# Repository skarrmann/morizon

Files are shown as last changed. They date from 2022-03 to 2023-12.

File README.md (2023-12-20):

# Morizon Keyboard

Morizon is a 5-row version of the Horizon keyboard.

This project is a direct modification of the Horizon project. The schematic and PCBs have been modified to support this 5-row layout.

As with Horizon, two separate PCB designs are available in the [`gerbers`](gerbers) folder: one for MX switches (19mm x 19mm spacing), and one for Choc switches (18mm x 17mm spacing).

Please refer to the [Horizon keyboard repository](https://github.com/skarrmann/horizon) for project documentation. Only Morizon-specific details are noted below!

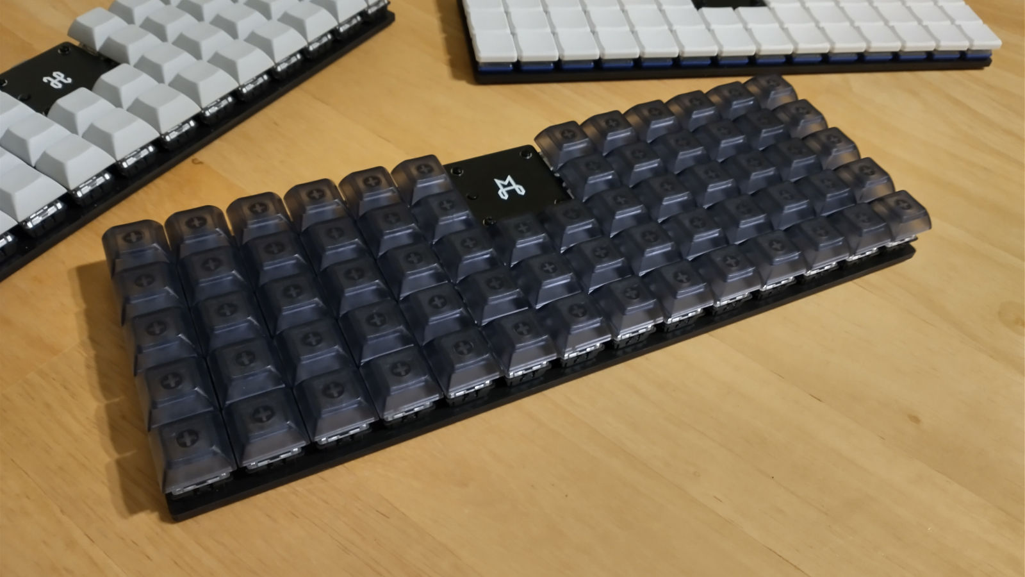
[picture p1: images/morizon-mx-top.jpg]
Morizon MX top photo


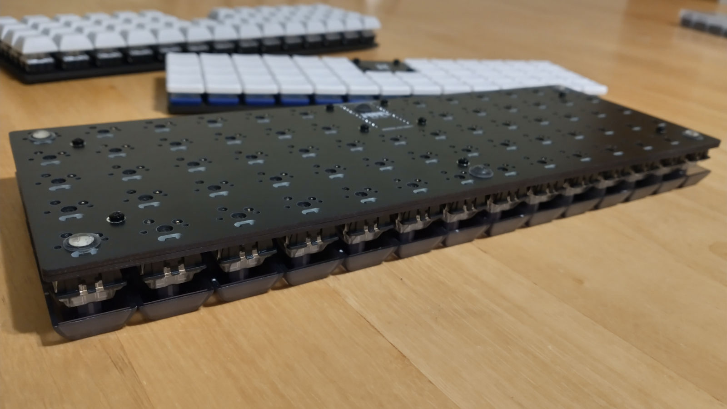
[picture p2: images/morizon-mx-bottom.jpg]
Morizon MX bottom photo


## Keyboard firmware

* [QMK](https://github.com/qmk/qmk_firmware/tree/master/keyboards/morizon)
* ZMK
    * Morizon shield definition is in [skarrmann's zmk-config](https://github.com/skarrmann/zmk-config)

## Bill of materials

Same as the [Horizon keyboard BOM](https://github.com/skarrmann/horizon/#bill-of-materials), but you will also need:

* Morizon PCBs (instead of Horizon PCBs)
* 14 more keyswitches
* 14 more keycaps
* 14 more 1N4148 SOD-123 diodes
* 1 more M2 6mm screw
* 1 more M2 nut

## Revision History

* **Rev1** (2022-02-05)
    * PCB: Create MX and Choc boards with bottom and top plates (based on Horizon).
    * Schematic: Wire as 66 key 10x7 matrix.
* **Rev1.1** (2022-03-21)
    * PCB, Schematic: No physical changes. Files upgraded to KiCad 6, and Gerber files regenerated using Horizon Board Producer 2.3.
* **Rev1.2** (2023-11-09)
    * PCB, Schematic: No physical changes. Files upgraded to KiCad 7, and Gerber files regenerated using Horizon Board Producer 2.4.

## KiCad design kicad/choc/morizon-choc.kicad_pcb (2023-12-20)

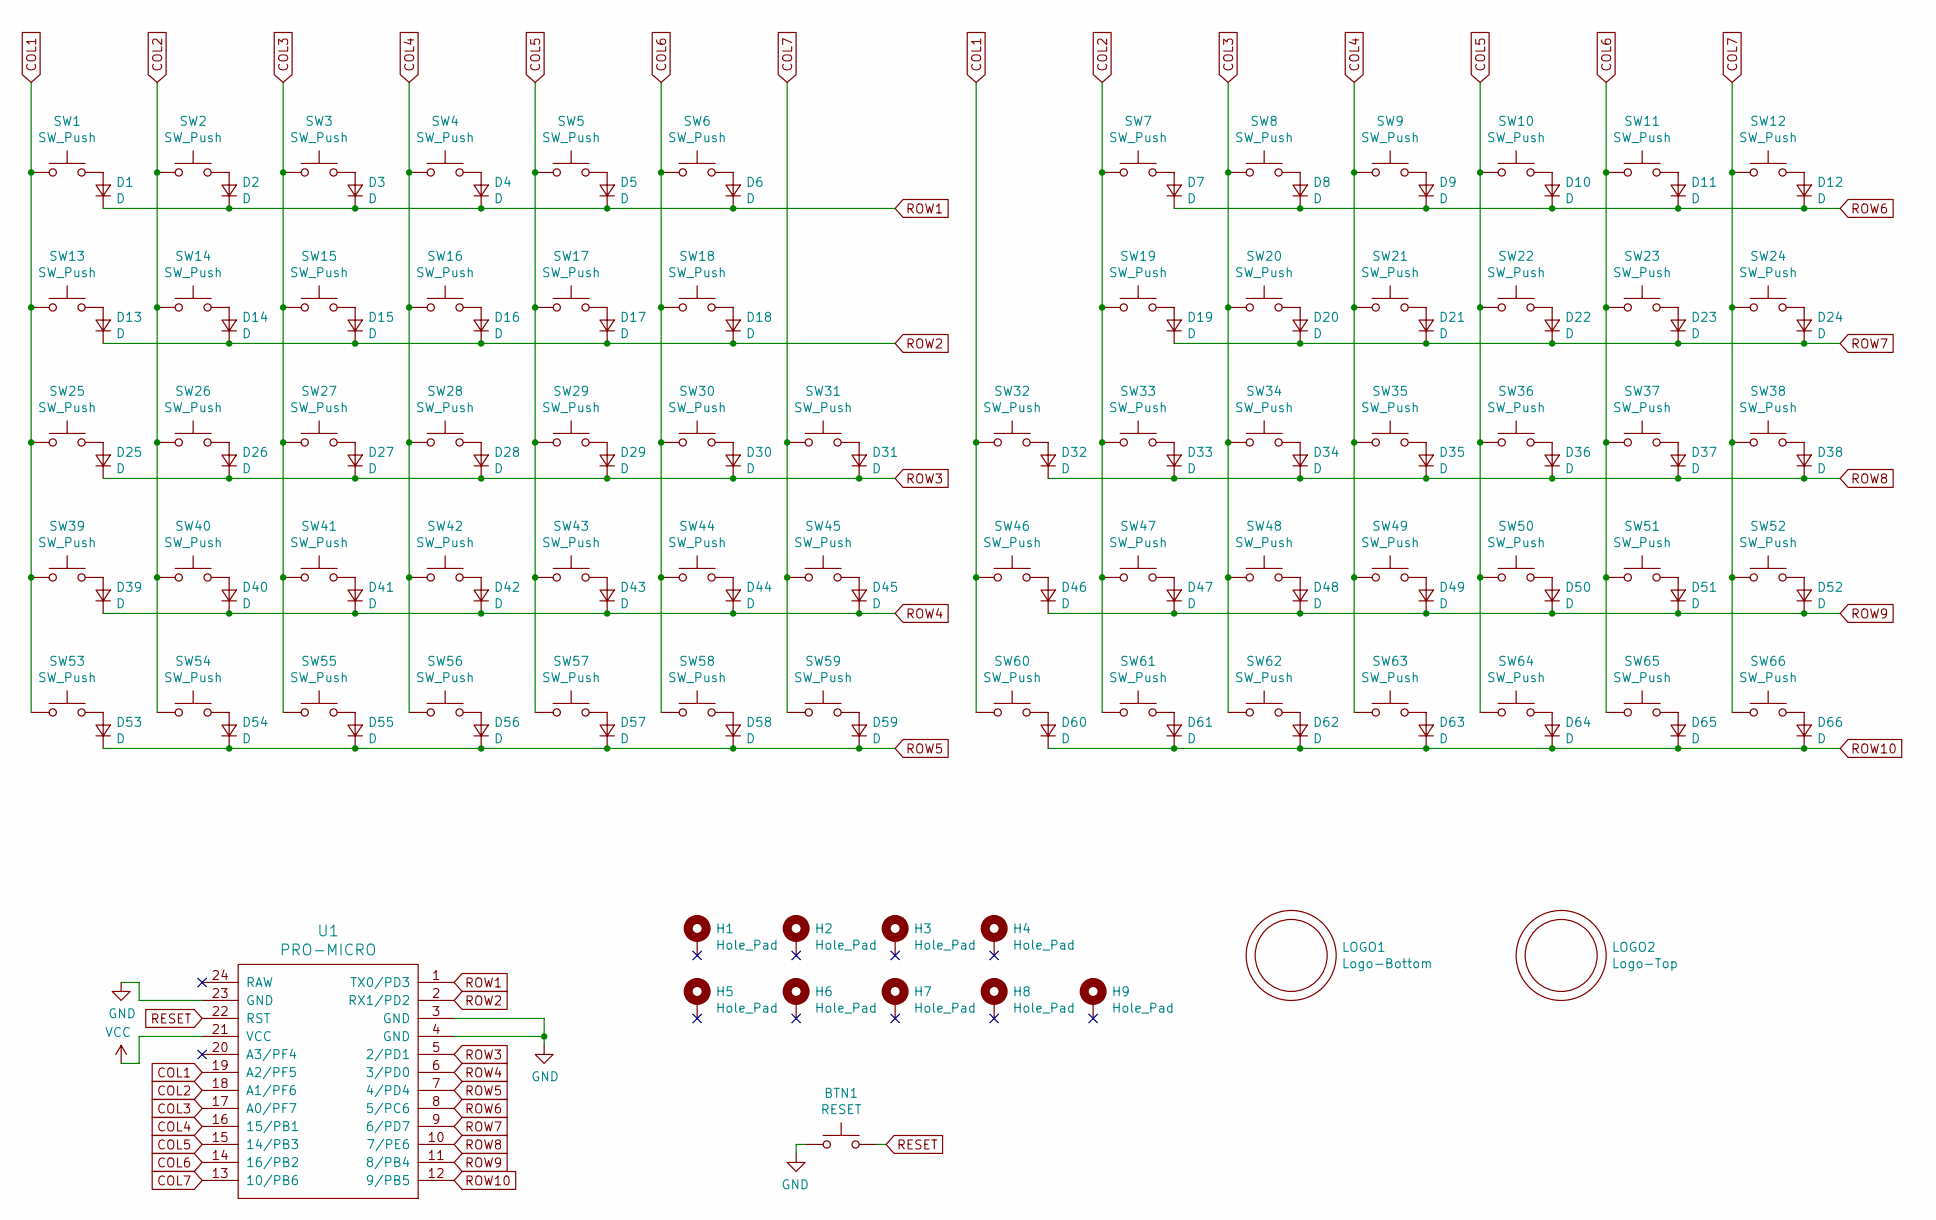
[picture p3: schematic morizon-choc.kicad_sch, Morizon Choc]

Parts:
BTN1: RESET; SW_Push_6mm
D1, D2, D3, D4, D5, D6, D7, D8, D9, D10, D11, D12, D13, D14, D15, D16, D17, D18, D19, D20, D21, D22, D23, D24, D25, D26, D27, D28, D29, D30, D31, D32, D33, D34, D35, D36, D37, D38, D39, D40, D41, D42, D43, D44, D45, D46, D47, D48, D49, D50, D51, D52, D53, D54, D55, D56, D57, D58, D59, D60, D61, D62, D63, D64, D65, D66: D; D_SOD-123
H1, H2, H3, H4, H5, H6, H7, H8, H9: Hole_Pad; Mount_M2
LOGO1: Logo-Bottom; Logo_Morizon_Small
LOGO2: Logo-Top; Logo_Morizon_M
SW1, SW2, SW3, SW4, SW5, SW6, SW7, SW8, SW9, SW10, SW11, SW12, SW13, SW14, SW15, SW16, SW17, SW18, SW19, SW20, SW21, SW22, SW23, SW24, SW25, SW26, SW27, SW28, SW29, SW30, SW31, SW32, SW33, SW34, SW35, SW36, SW37, SW38, SW39, SW40, SW41, SW42, SW43, SW44, SW45, SW46, SW47, SW48, SW49, SW50, SW51, SW52, SW53, SW54, SW55, SW56, SW57, SW58, SW59, SW60, SW61, SW62, SW63, SW64, SW65, SW66: SW_Push; SW_Choc
U1: PRO-MICRO; Pro-Micro

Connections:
COL1: SW1.1, SW13.1, SW25.1, SW32.1, SW39.1, SW46.1, SW53.1, SW60.1, U1.19 (A2/PF5)
COL2: SW2.1, SW7.1, SW14.1, SW19.1, SW26.1, SW33.1, SW40.1, SW47.1, SW54.1, SW61.1, U1.18 (A1/PF6)
COL3: SW3.1, SW8.1, SW15.1, SW20.1, SW27.1, SW34.1, SW41.1, SW48.1, SW55.1, SW62.1, U1.17 (A0/PF7)
COL4: SW4.1, SW9.1, SW16.1, SW21.1, SW28.1, SW35.1, SW42.1, SW49.1, SW56.1, SW63.1, U1.16 (15/PB1)
COL5: SW5.1, SW10.1, SW17.1, SW22.1, SW29.1, SW36.1, SW43.1, SW50.1, SW57.1, SW64.1, U1.15 (14/PB3)
COL6: SW6.1, SW11.1, SW18.1, SW23.1, SW30.1, SW37.1, SW44.1, SW51.1, SW58.1, SW65.1, U1.14 (16/PB2)
COL7: SW12.1, SW24.1, SW31.1, SW38.1, SW45.1, SW52.1, SW59.1, SW66.1, U1.13 (10/PB6)
GND: BTN1.2, U1.3 (GND), U1.4 (GND), U1.23 (GND)
unnamed: D1.2 (A), SW1.2
unnamed: D2.2 (A), SW2.2
unnamed: D3.2 (A), SW3.2
unnamed: D4.2 (A), SW4.2
unnamed: D5.2 (A), SW5.2
unnamed: D6.2 (A), SW6.2
unnamed: D7.2 (A), SW7.2
unnamed: D8.2 (A), SW8.2
unnamed: D9.2 (A), SW9.2
unnamed: D10.2 (A), SW10.2
unnamed: D11.2 (A), SW11.2
unnamed: D12.2 (A), SW12.2
unnamed: D13.2 (A), SW13.2
unnamed: D14.2 (A), SW14.2
unnamed: D15.2 (A), SW15.2
unnamed: D16.2 (A), SW16.2
unnamed: D17.2 (A), SW17.2
unnamed: D18.2 (A), SW18.2
unnamed: D19.2 (A), SW19.2
unnamed: D20.2 (A), SW20.2
unnamed: D21.2 (A), SW21.2
unnamed: D22.2 (A), SW22.2
unnamed: D23.2 (A), SW23.2
unnamed: D24.2 (A), SW24.2
unnamed: D25.2 (A), SW25.2
unnamed: D26.2 (A), SW26.2
unnamed: D27.2 (A), SW27.2
unnamed: D28.2 (A), SW28.2
unnamed: D29.2 (A), SW29.2
unnamed: D30.2 (A), SW30.2
unnamed: D31.2 (A), SW31.2
unnamed: D32.2 (A), SW32.2
unnamed: D33.2 (A), SW33.2
unnamed: D34.2 (A), SW34.2
unnamed: D35.2 (A), SW35.2
unnamed: D36.2 (A), SW36.2
unnamed: D37.2 (A), SW37.2
unnamed: D38.2 (A), SW38.2
unnamed: D39.2 (A), SW39.2
unnamed: D40.2 (A), SW40.2
unnamed: D41.2 (A), SW41.2
unnamed: D42.2 (A), SW42.2
unnamed: D43.2 (A), SW43.2
unnamed: D44.2 (A), SW44.2
unnamed: D45.2 (A), SW45.2
unnamed: D46.2 (A), SW46.2
unnamed: D47.2 (A), SW47.2
unnamed: D48.2 (A), SW48.2
unnamed: D49.2 (A), SW49.2
unnamed: D50.2 (A), SW50.2
unnamed: D51.2 (A), SW51.2
unnamed: D52.2 (A), SW52.2
unnamed: D53.2 (A), SW53.2
unnamed: D54.2 (A), SW54.2
unnamed: D55.2 (A), SW55.2
unnamed: D56.2 (A), SW56.2
unnamed: D57.2 (A), SW57.2
unnamed: D58.2 (A), SW58.2
unnamed: D59.2 (A), SW59.2
unnamed: D60.2 (A), SW60.2
unnamed: D61.2 (A), SW61.2
unnamed: D62.2 (A), SW62.2
unnamed: D63.2 (A), SW63.2
unnamed: D64.2 (A), SW64.2
unnamed: D65.2 (A), SW65.2
unnamed: D66.2 (A), SW66.2
RESET: BTN1.1, U1.22 (RST)
ROW1: D1.1 (K), D2.1 (K), D3.1 (K), D4.1 (K), D5.1 (K), D6.1 (K), U1.1 (TX0/PD3)
ROW2: D13.1 (K), D14.1 (K), D15.1 (K), D16.1 (K), D17.1 (K), D18.1 (K), U1.2 (RX1/PD2)
ROW3: D25.1 (K), D26.1 (K), D27.1 (K), D28.1 (K), D29.1 (K), D30.1 (K), D31.1 (K), U1.5 (2/PD1)
ROW4: D39.1 (K), D40.1 (K), D41.1 (K), D42.1 (K), D43.1 (K), D44.1 (K), D45.1 (K), U1.6 (3/PD0)
ROW5: D53.1 (K), D54.1 (K), D55.1 (K), D56.1 (K), D57.1 (K), D58.1 (K), D59.1 (K), U1.7 (4/PD4)
ROW6: D7.1 (K), D8.1 (K), D9.1 (K), D10.1 (K), D11.1 (K), D12.1 (K), U1.8 (5/PC6)
ROW7: D19.1 (K), D20.1 (K), D21.1 (K), D22.1 (K), D23.1 (K), D24.1 (K), U1.9 (6/PD7)
ROW8: D32.1 (K), D33.1 (K), D34.1 (K), D35.1 (K), D36.1 (K), D37.1 (K), D38.1 (K), U1.10 (7/PE6)
ROW9: D46.1 (K), D47.1 (K), D48.1 (K), D49.1 (K), D50.1 (K), D51.1 (K), D52.1 (K), U1.11 (8/PB4)
ROW10: D60.1 (K), D61.1 (K), D62.1 (K), D63.1 (K), D64.1 (K), D65.1 (K), D66.1 (K), U1.12 (9/PB5)

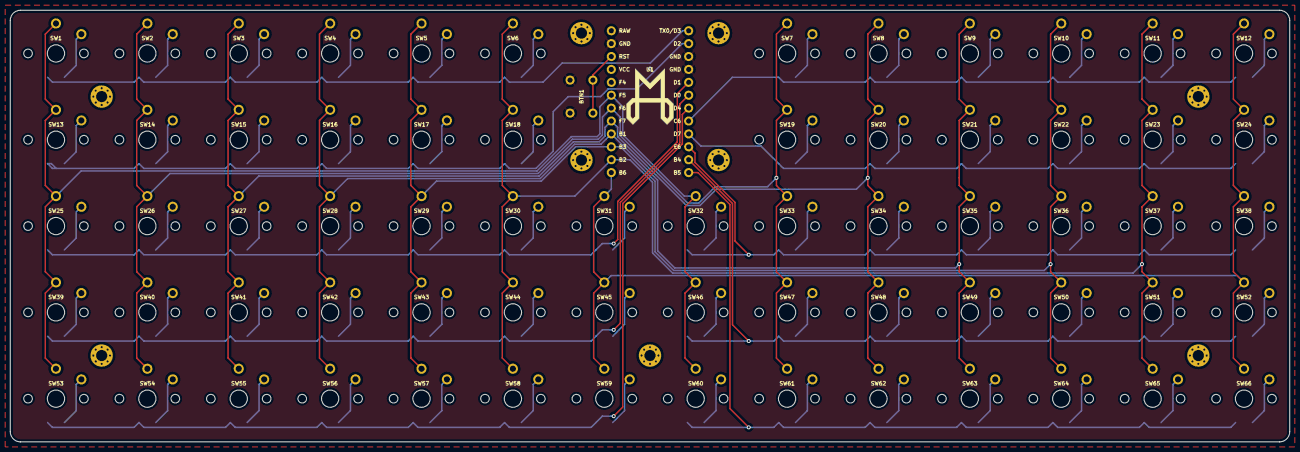
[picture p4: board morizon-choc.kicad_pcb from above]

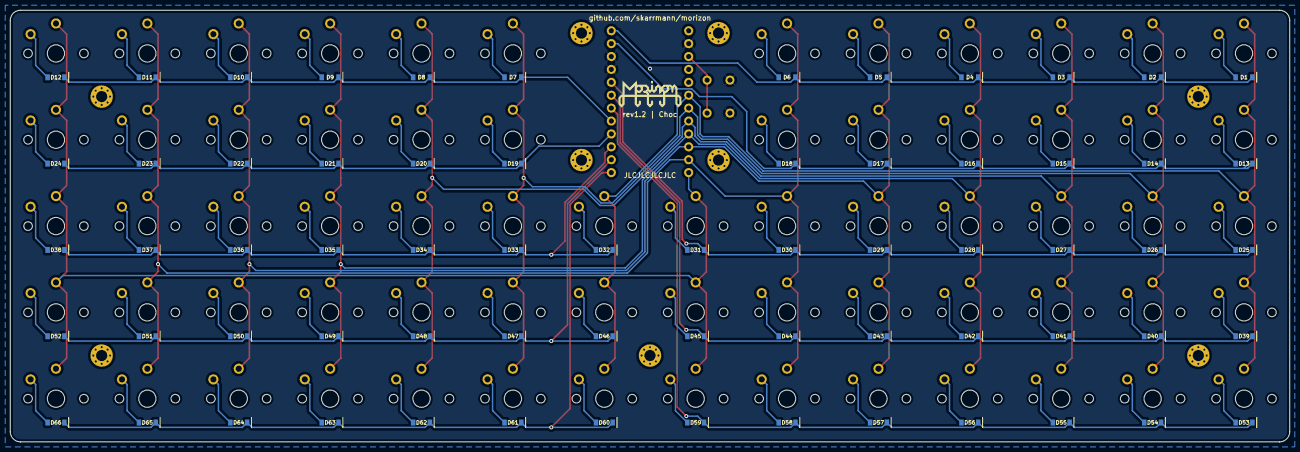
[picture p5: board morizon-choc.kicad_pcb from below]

Board: 2 copper layers, 252.0 x 85.0 mm, 145 parts (67 on the bottom side), 85 nets.

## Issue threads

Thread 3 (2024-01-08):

No keystrokes recorded

maximilienGilet, 2024-01-08:
Hi

I've built a Morizon following the BOM and flashing guide. I successfully flashed the pro micro (showing `HID console connected: Steven Karrmann Morizon (FEED:0000:0001)` in QMK Toolbox).

However I don't get any keys recorded. I tried re-flashing multiple times and double checked the diodes but nothing seems to work.

What could be the issue ?

skarrmann, 2024-01-08:
Hello!

I will confirm the Morizon firmware flash works with QMK Toolbox within a couple days, hopefully tonight. QMK Toolbox worked when I last tried it about a year ago, and QMK CLI works.

Which model Pro Micro are you using? Did you use sockets to connect it the PCB? If so, I recommend removing the Pro Micro and testing it separately. Use a wire to connect pins 14 (B3) and 7 (E6) - this should send keystroke for letter "L". If the Pro Micro works while removed from the PCB, then it is a PCB or soldering issue. If the Pro Micro does not work while removed from the PCB, then it is an issue with the microcontroller or the firmware.

Please let me know how your testing goes, and I will try flashing using the QMK Toolbox soon and let you know how that works.

skarrmann, 2024-01-08:
I testing flashing the Morizon firmware with QMK Toolbox. It worked for me, and keystrokes work afterwards. Here is what I did:

1. Download and install [qmk_toolbox_install.exe](https://github.com/qmk/qmk_toolbox/releases/download/0.2.2/qmk_toolbox_install.exe).
2. When running QMK Toolbox for the first time, a prompt appeared: "Would you like to install drivers for your devices?". Click "Yes", and waited for the drivers to install.
3. Compile and download the [default Morizon layout firmware from QMK Configurator](https://config.qmk.fm/#/morizon/LAYOUT).
4. In QMK Toolbox, open the firmware file.
5. Connect the Morizon keyboard to the PC. (My Pro Micro is has a blue PCB and USB Micro port)
6. Press the reset button on the Morizon PCB, and then in QMK Toolbox click the "Flash" button.

After flashing finished, the keyboard worked with the default layout loaded. In case it helps, here is my output from flashing in QMK Toolbox:
```
Caterina device connected (usbser): Microsoft USB Serial Device (COM3) (2341:0037:0001) [COM3]
Attempting to flash, please don't remove device
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
Flash complete
HID console connected: Steven Karrmann Morizon (FEED:0000:0001)
```

So it seems the default Morizon firmware is okay, and it can be installed with QMK Toolbox.

Let me know how your testing goes.

skarrmann, 2024-01-22:
@maximilienGilet Have you had a chance to further troubleshoot this issue?

skarrmann, 2024-02-13:
I am closing this issue since I cannot reproduce it, and have received no reply. The Morizon PCB and flashing the firmware with QMK Toolbox on a Pro Micro worked in my testing above.

@maximilienGilet If you are still having an issue, experienced QMK users may be able to help troubleshoot. My advice above might help diagnose the issue. Good luck!

maximilienGilet, 2024-02-23:
Hi @skarrmann, sorry for the delay I have been quite busy since then and didn't received Github notifications.

I have this exact pro micro (with USB C) : https://fr.aliexpress.com/item/32846843498.html

maximilienGilet, 2024-02-26:
Hi @skarrmann, I just tested the pro micro and the pin 7 + 14 shortcut works, it triggers an L.
I will check my soldering again

skarrmann, 2024-02-26:
@maximilienGilet That is good! Then there is likely is a soldering issue. A multimeter would be helpful for checking electrical continuity between pins and confirming there are no solder bridges. Good luck!

maximilienGilet, 2024-02-26:
Hi again @skarrmann !
After a lot of tinkering i figured out that inverting the diodes position makes it working somehow, but the matrix is inverted.

As i'm typing this I think it might not be the diodes but the pro micro needing to be flipped (I soldered it with the components on the upper side). Could it be that ?

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

skarrmann, 2024-02-26:
Yes, that is the issue! The Pro Micro needs to be soldered with the components facing down, so its pin labels match the labels printed on the PCB.

I am glad you discovered the problem, and I hope you can fix it without too much trouble.

maximilienGilet, 2024-02-27:
Thank you for your help !

Closed 2024-02-13.

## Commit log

2022-02-05 Initial commit copied from Horizon. Update readme and create logo SVGs
    [horizon-choc.kicad_pcb, horizon-choc.sch, horizon-mx.kicad_pcb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]
2022-02-05 Implement Morizon Choc
    [horizon-choc.kicad_pcb, horizon-choc.sch, morizon-choc.kicad_pcb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]
2022-02-06 Implement Morizon MX
    [morizon-choc.kicad_pcb, morizon-mx.kicad_pcb, morizon-mx.sch]
2022-02-06 Note current status in readme
2022-02-10 Note PCBs ordered from JLCPCB
2022-03-02 Note PCBs arrived
2022-03-21 Upgrade project files to KiCad 6
    [morizon-choc.kicad_pcb, morizon-choc.kicad_sch, morizon-choc.sch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]
2022-03-21 Use KiCad 6 symbol library format
    [morizon-choc.kicad_sch, morizon-mx.kicad_sch]
2023-11-10 Upgrade project files to KiCad 7
    [morizon-choc.kicad_pcb, morizon-choc.kicad_sch, morizon-mx.kicad_pcb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]
2023-12-20 Remove Horizon board producer plugin (it is manages in Horizon repo)
